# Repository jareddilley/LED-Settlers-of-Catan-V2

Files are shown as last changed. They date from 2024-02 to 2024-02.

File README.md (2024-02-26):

# LED-Settlers-of-Catan-V2


Fully 3D printed 5-6 person LED Settlers of Catan - Fully interactive game board that's fun for the whole family.

This is version two of my LED Settlers of Catan that I design and built from scratch. For those who have played Catan know that setting up the game takes a while. This board removed that with set up in an instant. Along with instant set up, the LEDs add to a great game aesthetic. This is the version 2 of the board. Version 2 is better is every way: plays up to 6 people, more compact, better aesthetics, simpler robust construction. Version 2 also has an ESP32 microcontroller so in the future I can possibly make an app that Bluetooth to the board. This GitHub contains all the code and 3D files if anyone wants to try and build their own. If you are interested in how it was build and want to be entertained at the same time, watch the YouTube video: https://www.youtube.com/watch?v=XWqmaW1D9r8

Below is the Fritzing [Schematics](https://github.com/jareddilley/LED-Settlers-of-Catan-V2/tree/main/Schematics) wiring diagram for anyone looking to build thier own.
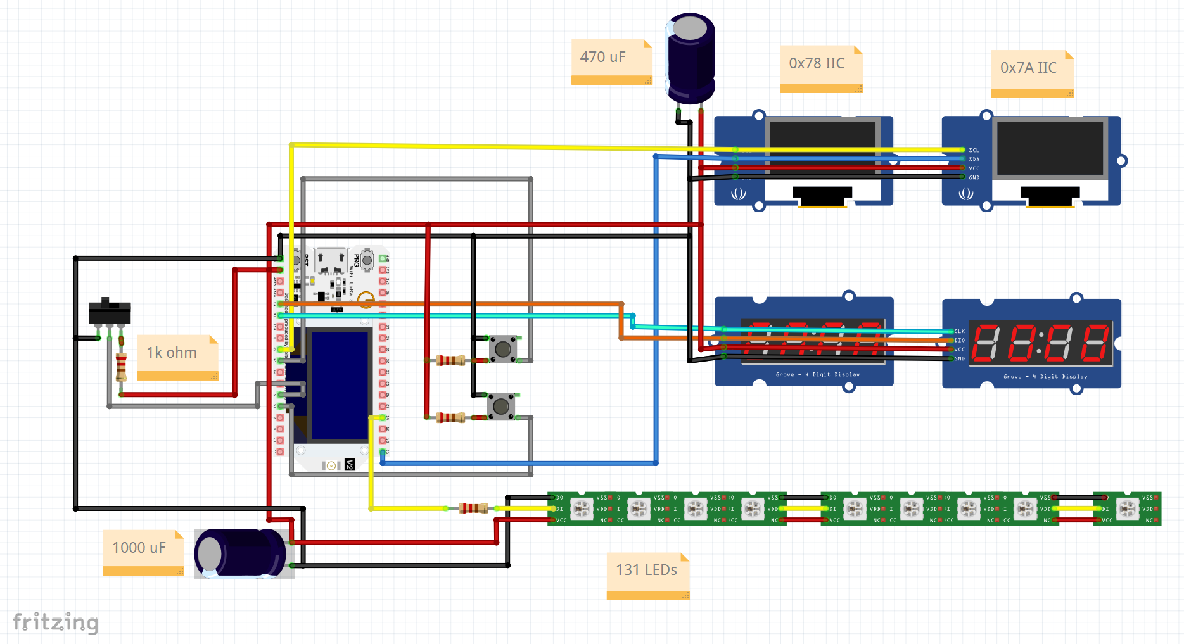
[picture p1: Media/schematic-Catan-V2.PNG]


# Game Modes


There is a switch to choose between two different game board layouts. The first mode randomly generates the game board, but makes sure no resource tile of the same type are next to each other. The second made also randomly generates the game board, but there are no restrictions and same resource types can be next to each other. The game modes can only be changed before powering up the board. The switch allows people to choose how they want to play, and it also changes what happens when a 7 is rolled. 

# Rolling a 7


With this new board, I chose to remove the idea of the robber. In addition to no robber, there is also a new hexagon that replaces one of the deserts. The hexagon is purple and allows you to choose a resource when the number on the spot is rolled. Now when a seven is rolled it changes the location of the desert and the all hex. For the evenly spread out game mode, the desert and the all hex switch places. For the fully random game mode, the desert and the all spot trade places with a random spot on the board. This changes the way the board is played, either setting people back or allowing them to pull forward. This also reduces anger between players since you can't get picked on by the robber. 

# Graphical Displays


The version 2 upgraded the pre-existing info displays. Version 1 of the board had a list of each resource and how much each has been rolled. Version 2 has two graphical displays. One is a bar char that shows the resources rolled, and the other is a bar chart showing the distribution of the dice rolls. These graphical displays add stats that allow you to see which dice rolls are being favored and which resources are dominating. 

# LED PCBs
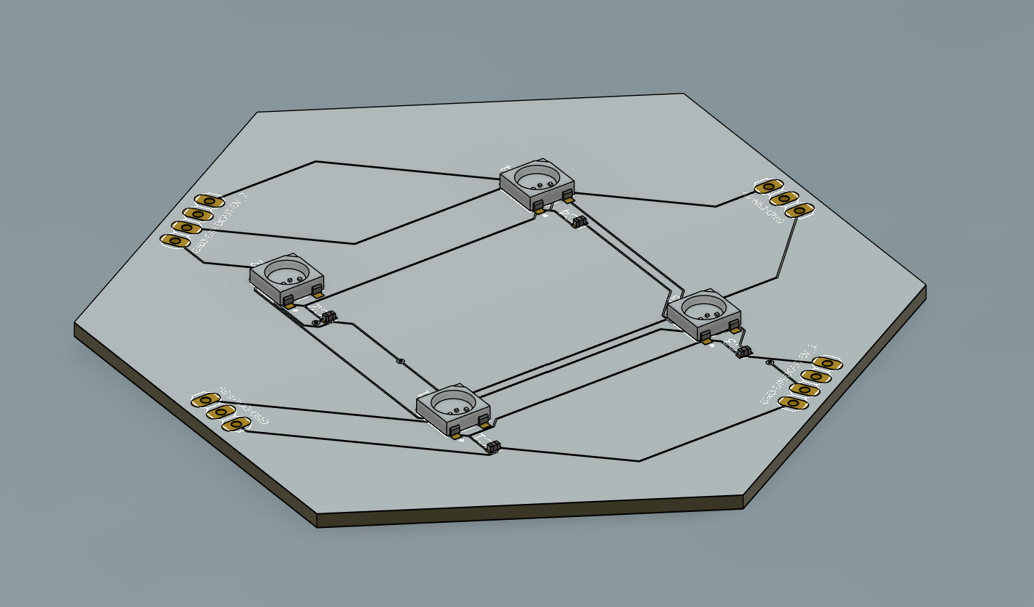
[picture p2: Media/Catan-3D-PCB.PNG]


Building these boards from scratch takes a lot of time. Version 1 used LED strips for the lighting that was very time-consuming to wire up. In this build, I went with designing my own PCBs for the LEDs that allowed for quick and easy assembly. The new PCB are white, which allows them to be LEDs and reflectors in one. I ordered my PCBs from JLCPCB, so if anyone is interested in ordering the same design, I put the zipped folder in the [Schematics](https://github.com/jareddilley/LED-Settlers-of-Catan-V2/tree/main/Schematics) directory.

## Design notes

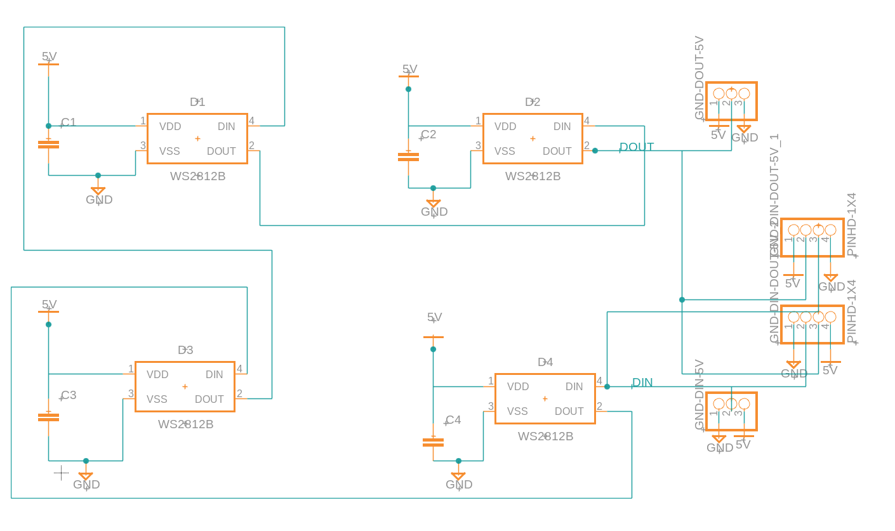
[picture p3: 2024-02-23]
Media/Catan-PCB-schematic.PNG

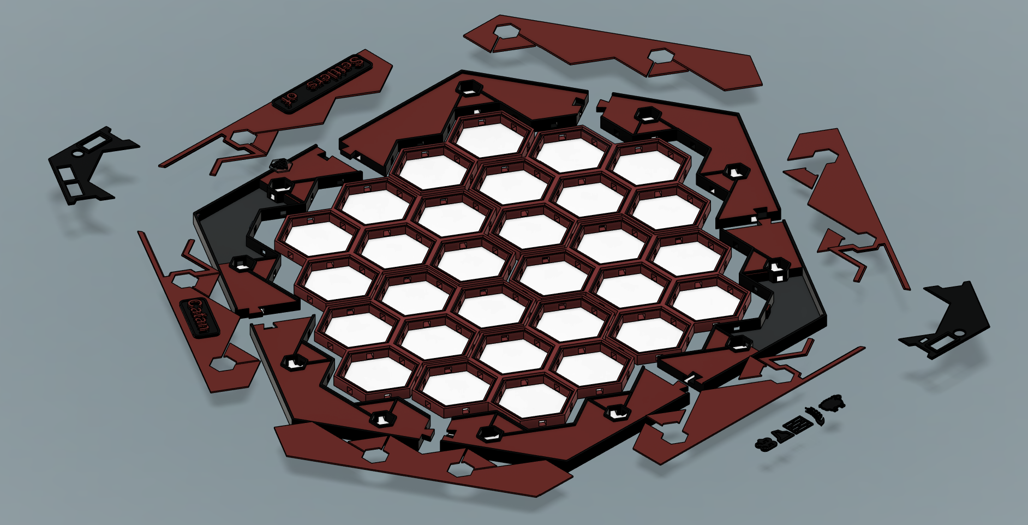
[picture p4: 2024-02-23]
Media/Catan-Fusion360.PNG

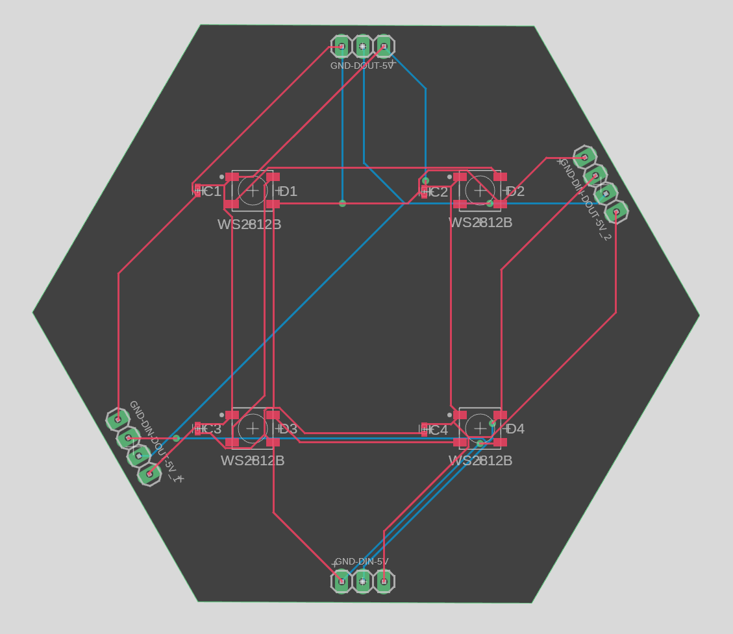
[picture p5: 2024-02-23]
Media/Catan-2D-PCB.PNG

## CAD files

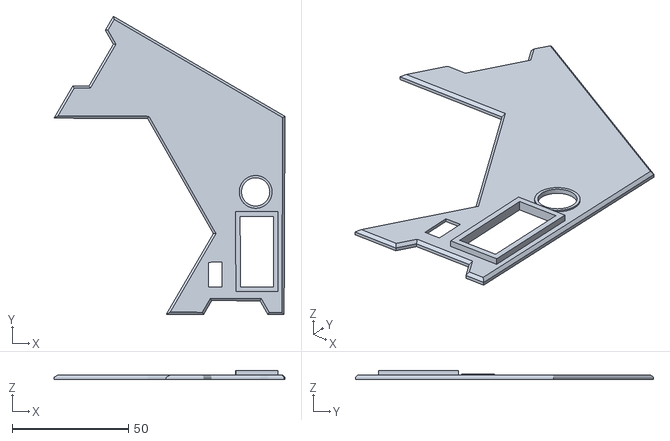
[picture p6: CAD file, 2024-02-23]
STL files/Boarders/cover-main.stl
99.6 x 128.6 x 4.00

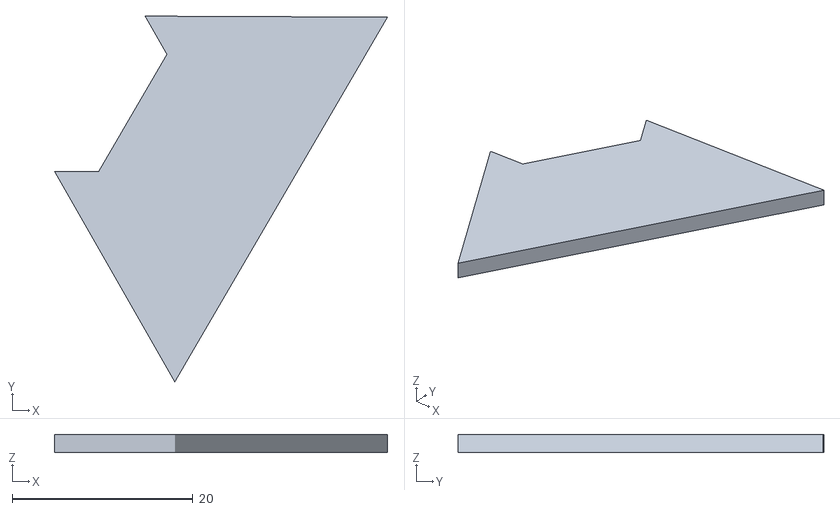
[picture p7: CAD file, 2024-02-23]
STL files/Boarders/Water-2 diff.stl
36.8 x 40.5 x 2.00

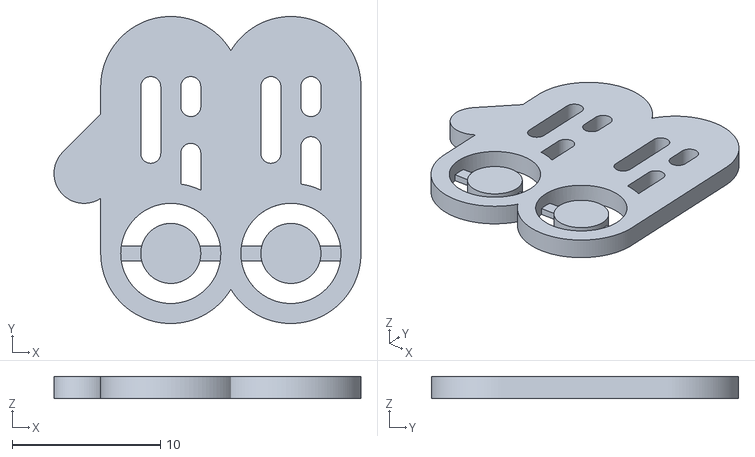
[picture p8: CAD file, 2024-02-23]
STL files/Decals/log (1).stl
20.7 x 20.7 x 1.50

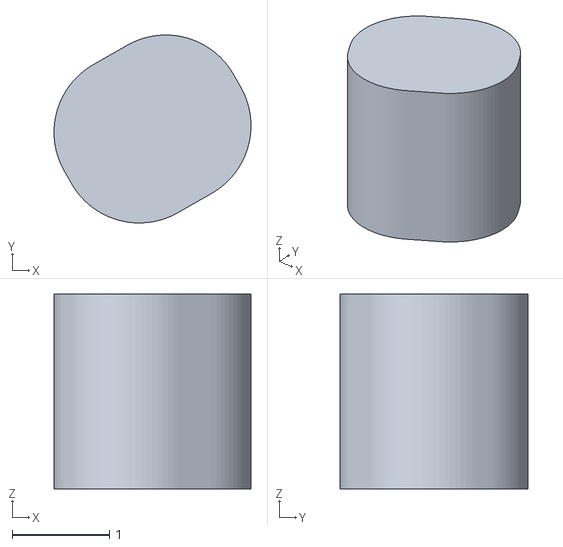
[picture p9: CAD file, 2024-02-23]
STL files/Main Board/1-Dot.stl
2.02 x 1.93 x 2.00

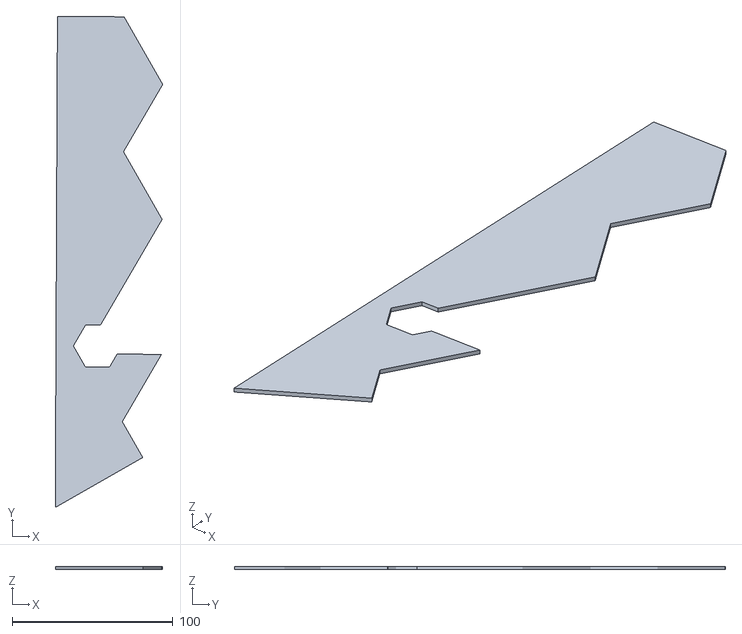
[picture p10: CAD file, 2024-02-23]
STL files/Boarders/Water-6 (1).stl
66.8 x 305.2 x 2.00

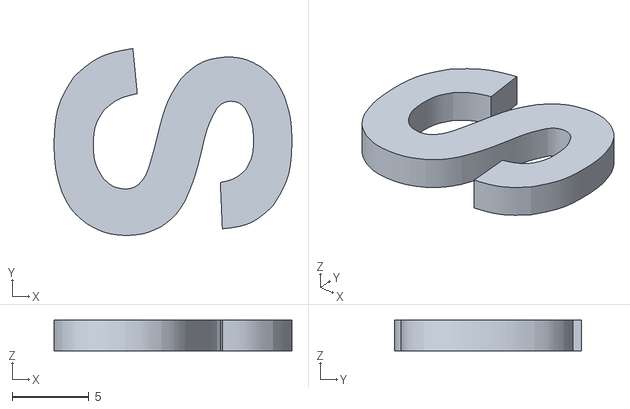
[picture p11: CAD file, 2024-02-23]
STL files/Decals/Cap S.stl
15.5 x 12.2 x 2.00

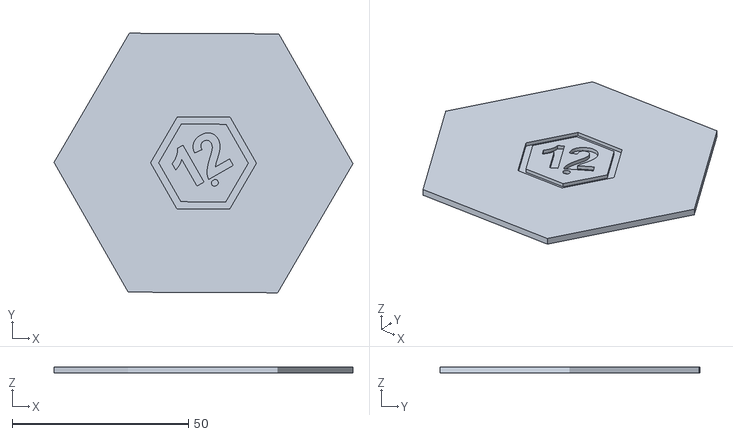
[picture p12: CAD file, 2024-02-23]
STL files/Main Board/Diffuser-12.stl
84.7 x 73.6 x 1.75

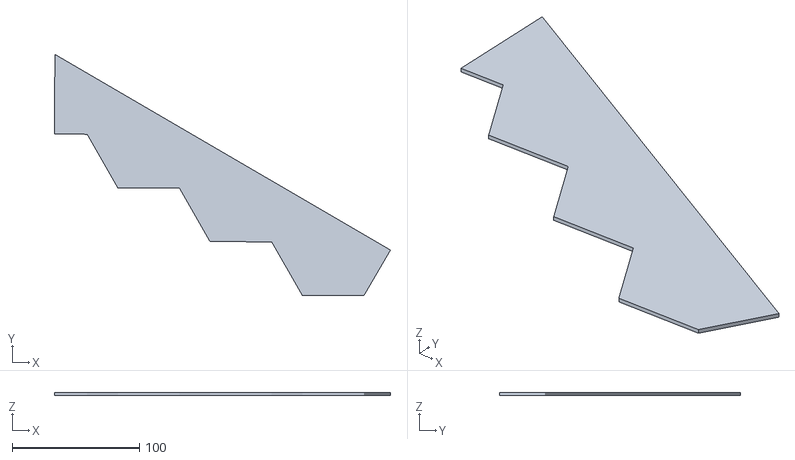
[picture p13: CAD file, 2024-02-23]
STL files/Boarders/Water-3.stl
263.9 x 189.5 x 2.00

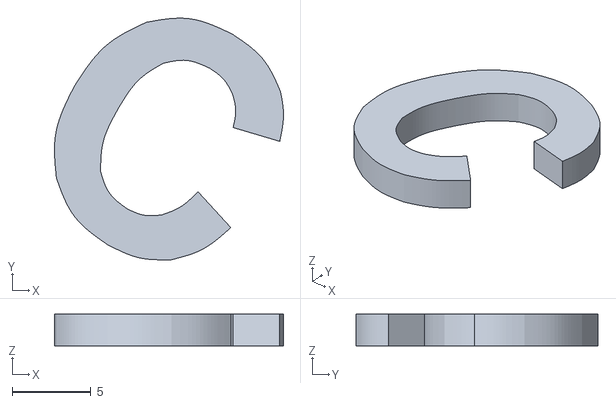
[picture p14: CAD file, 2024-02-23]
STL files/Decals/C.stl
14.5 x 15.3 x 2.00

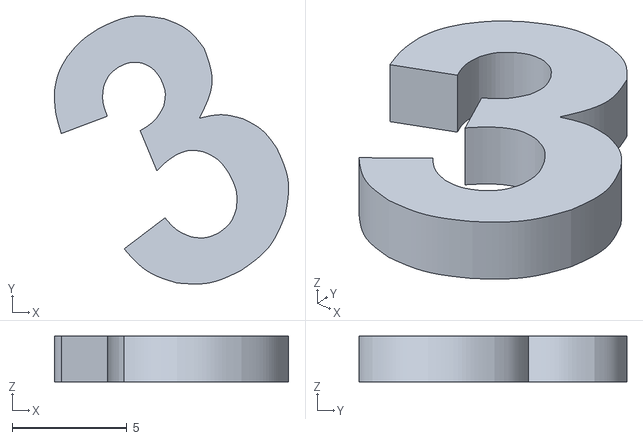
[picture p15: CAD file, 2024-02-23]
STL files/Main Board/3.stl
10.2 x 11.7 x 2.00

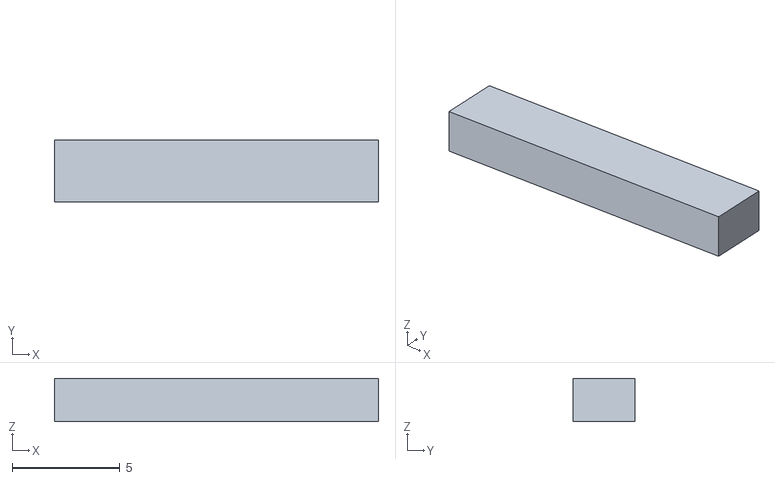
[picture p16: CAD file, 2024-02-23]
STL files/Decals/l.stl
15.0 x 2.88 x 2.00

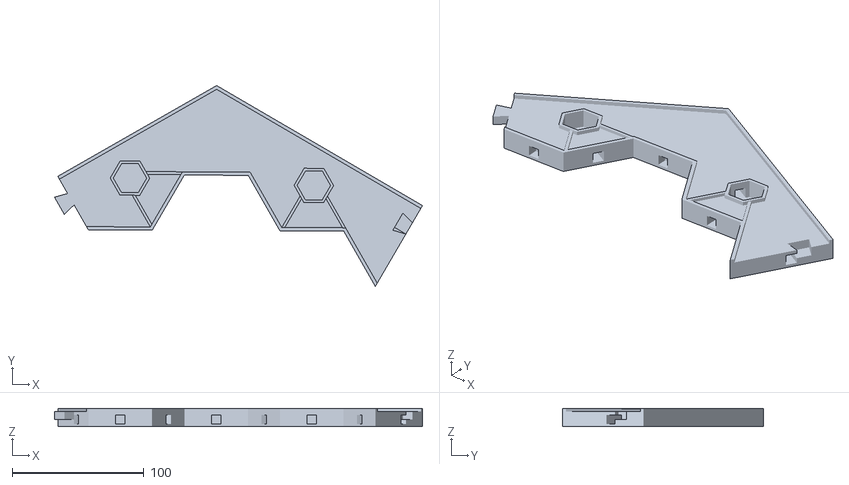
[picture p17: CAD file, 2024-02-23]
STL files/Boarders/Boarder-2.stl
279.2 x 152.5 x 14.0

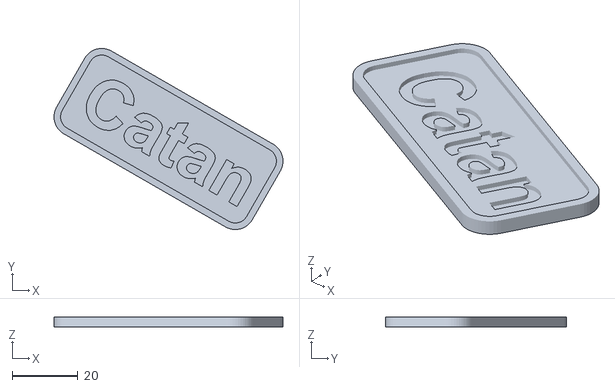
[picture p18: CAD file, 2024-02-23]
STL files/Decals/Catan.stl
69.8 x 55.2 x 3.00

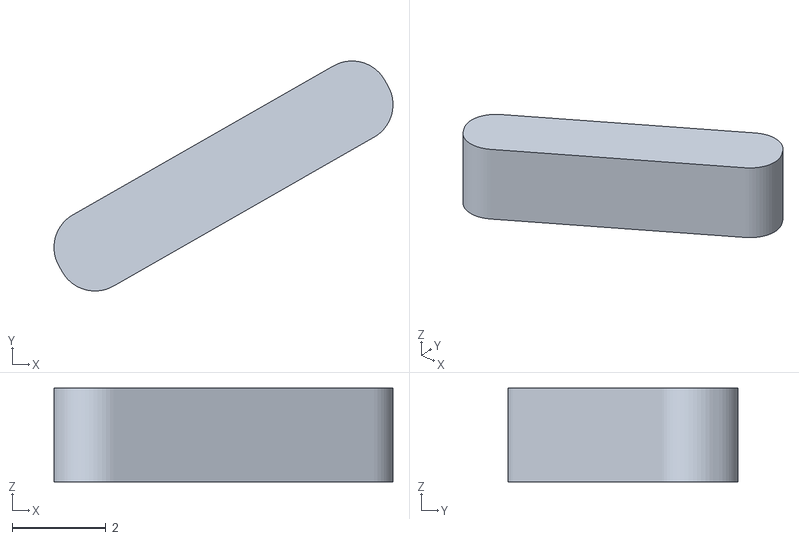
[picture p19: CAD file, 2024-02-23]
STL files/Main Board/4-Dot.stl
7.23 x 4.90 x 2.00

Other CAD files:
STL files/Main Board/Diffuser-3.stl
STL files/Decals/Boat.stl
STL files/Main Board/Diffuser-4.stl
STL files/Boarders/cover-other.stl
STL files/Boarders/Boarder-1 (1).stl
STL files/Boarders/Boarder-1.stl
STL files/Boarders/Boarder-2 (1).stl
STL files/Boarders/Boarder-3 (1).stl
STL files/Boarders/Boarder-3.stl
STL files/Boarders/Water-1.stl
STL files/Boarders/Water-2.stl
STL files/Boarders/Water-3 (2).stl
STL files/Boarders/Water-4.stl
STL files/Boarders/Water-5 (1).stl
STL files/Boarders/Water-5-other.stl
STL files/Boarders/Water-5.stl
STL files/Boarders/Water-6 (1)-other.stl
STL files/Decals/Port-Diffuser.stl
STL files/Decals/Settlers of.stl
STL files/Decals/a.stl
STL files/Decals/brick (1).stl
STL files/Decals/e.stl
STL files/Decals/f.stl
STL files/Decals/n.stl
STL files/Decals/o.stl
STL files/Decals/r.stl
STL files/Decals/rock (1).stl
STL files/Decals/s.stl
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

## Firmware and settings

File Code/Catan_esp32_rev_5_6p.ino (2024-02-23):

/**
Version 2 LED Catan - 5-6 person board size with desert included in board generation
Inludes additional rules and game aspects and a new resoruce hex (the all recource spot)
Board - 38 Pin ESP32 (Wi-fi and Bluetooth capable)
Author - Jared Dilley
**/

#include <FastLED.h>
#include <TM1637.h>
#include <SPI.h>
#include <Wire.h>
#include <Adafruit_GFX.h>
#include <Adafruit_SSD1306.h>
#include <stdlib.h>
#include <time.h>
#include <stdio.h>

#define SCREEN_WIDTH 128 // OLED display width, in pixels
#define SCREEN_HEIGHT 32 // OLED display height, in pixels
#define OLED_RESET -1 // Reset pin # (or -1 if sharing Arduino reset pin)
#define NUM_LEDS 131  // Total num of LEDs
#define spotSize 4  // num of LEDs per hex
#define LED_PIN 14
#define Button 19   // Roll Dice Button 1
#define Button2 15  // Roll Dice Button 2   
#define Mode 5      // Switch for game mode
int ButtonState;
int ButtonState2;
int brightness = 50;
const int range = 30; // number of hexagons
const int num_ports = 11;  // number of ports
int tracker = 0;
unsigned long now = millis();
int CLK = 1;
int DIO = 3;  
TM1637 tm(CLK,DIO); // TX, RX
Adafruit_SSD1306 display1(-1);  // SCL P22, SDA P21
Adafruit_SSD1306 display2(-1);
int offset = 8;
int offset2 = 7;
int brick = 0; 
int wheat = 0; 
int wood = 0; 
int rock = 0; 
int sheep = 0;
int ModeState;
int rolls[11] = {0,0,0,0,0,0,0,0,0,0,0};  // tracker for the dice rolls 2-12
int button_display[12] = {0,1,2,3,4,14,15,25,26,27,28,29};
int button2_display[12] = {26,27,28,29,21,20,9,8,0,1,2,3};



// Brick::Red, Boulder::Aqua, Logs::Green, Hay::Orange, Sheep::white, Desert::Black
uint32_t resource[range];
uint32_t resource_rand[range] = {CRGB::Red,CRGB::Red,CRGB::Red,CRGB::Red,CRGB::Red,CRGB::Aqua,CRGB::Aqua,CRGB::Aqua,CRGB::Aqua,CRGB::Aqua,
CRGB::Green,CRGB::Green,CRGB::Green,CRGB::Green,CRGB::Green,CRGB::Green,CRGB::Orange,CRGB::Orange,CRGB::Orange,CRGB::Orange,CRGB::Orange,CRGB::Orange,
CRGB::White,CRGB::White,CRGB::White,CRGB::White,CRGB::White,CRGB::White,CRGB::Black,CRGB::Purple};
uint32_t resource_spread[range] = {3,4,2,3,5,4,3,5,1,2,4,1,CRGB::Black,2,4,1,5,3,5,CRGB::Purple,1,3,2,1,4,2,5,3,4,5};
uint32_t five_spot[2] = {CRGB::Red,CRGB::Aqua};
uint32_t six_spot[3] = {CRGB::Green,CRGB::Orange,CRGB::White};
CRGB all[5] = {CRGB::Red,CRGB::Green,CRGB::Orange,CRGB::Aqua,CRGB::White};
int values[range] = {11,12,9,8,9,2,4,10,6,12,11,8,5,6,3,5,12,4,2,9,4,2,3,10,8,10,3,11,6,5}; // values of all 30 spots
int spotValues[range];
CRGB leds[NUM_LEDS];
CRGB currentColors[range];

// Function to swap two elements in an array
void swap_uint(uint32_t  *a, uint32_t  *b) {
    uint32_t  temp = *a;
    *a = *b;
    *b = temp;
}

// Function to the elements in a given array
void shuffle(uint32_t arr[], int size){
  for (int i = size - 1; i > 0; i--) {
    // Generate a random index between 0 and i (inclusive)
    int j = random(0,1000) % (i + 1);
    // Swap current element with randomly generated element
    swap_uint(&arr[i], &arr[j]);
  }
}

// Function to find an element in an array and swap it with a random element
void swapWithRandom(CRGB arr[], int size, CRGB target) {
  // Search for the target element in the array
  int found = 0;
  int targetIndex;
  for (int i = 0; i < size; i++) {
    if (arr[i] == target) {
      targetIndex = i; // Store the index of the target element
      found = 1;
      break;
    }
  }
  // If the target element was found, swap it with a random element
  if (found) {
    int randomIndex = random(0,1000) % size;
    CRGB target_spot = currentColors[targetIndex];
    CRGB rand_spot = currentColors[randomIndex];
    for (int i = 0; i < 2; i++) {  
      setSpot(targetIndex + 1, CRGB::Black, false);
      setSpot(randomIndex + 1, CRGB::Black, false);
      FastLED.show();
      delay(250);
      setSpot(targetIndex + 1, target_spot, false);
      setSpot(randomIndex + 1, rand_spot, false);
      FastLED.show();
      delay(250);
    }
    for (int i = 0; i < 2; i++) {  
      setSpot(targetIndex + 1, CRGB::Black, false);
      setSpot(randomIndex + 1, CRGB::Black, false);
      FastLED.show();
      delay(250);
      setSpot(targetIndex + 1, rand_spot, true);
      setSpot(randomIndex + 1, target_spot, true);
      FastLED.show();
      delay(250);
    }
  }
}

// Sets the specified hexagon, with an option to save changes to memory
void setSpot (int spot, CRGB color, boolean save){  
    int currentLED = (spot - 1)*spotSize + num_ports;
    int lastLED = currentLED + spotSize; 
    for (currentLED; currentLED < lastLED; currentLED++) {   
      leds[currentLED] = color;
    }
    if (save){
      currentColors[spot-1] = color; 
    }
}

// Returns True if element in array
boolean arrayIncludeElement(int randArray[], int input, int range) {
  for (int i = 0; i < range; i++) {   
    if (randArray[i] == input) {
      return true;
    }
  }
  return false;
}

// Fuction for rolling the dice and playing animations
void rollDice() {
  // Roll dice
  int roll = random(1,7) + random(1,7);
  // roll = 7; // uncomment for testing 7's
  rolls[roll-2]++;
  tm.init(); // clear
  if (roll < 10){
    tm.display(3,roll);
  } else{
    tm.display(2,1);
    tm.display(3,roll-10);
  }
  // show dice value
  for (int i = 0; i < range; i++) {   
    setSpot(i+1, CRGB::Black, false);
  }
  FastLED.show();  
  
  for (int i = 0; i < roll; i++) {   // rev
    if(ButtonState == LOW){
      setSpot(button_display[i]+1, CRGB::White, false);
    } else if (ButtonState2 == LOW){
      setSpot(button2_display[i]+1, CRGB::White, false);
    }
    FastLED.show();
    delay(100);
  }
  delay(500);
  // show only spots with that roll
  int locations[range];
  int count = 0;
  if (roll == 7){
    updateDisplay(brick, wheat, wood, rock, sheep);
    for (int a = 0; a < 3; a++) {
      for (int i = 0; i < range; i++) {   
        setSpot(i+1, CRGB::Red, false);
      }
      FastLED.show();
      delay(500);
      if (a < 2){
        for (int i = 0; i < range; i++) {   
          setSpot(i+1, CRGB::Black, false);
        }
        FastLED.show();
        delay(500);
      }
    }
    if (ModeState == HIGH){ // randomly swap desert and all piece with a random piece
      swapWithRandom(currentColors, range, CRGB::Black);
      swapWithRandom(currentColors, range, CRGB::Purple);
    } else{ // swap desert and all rec in even spread
      CRGB spot_19 = currentColors[19];
      CRGB spot_12 = currentColors[12];
      for (int i = 0; i < 2; i++) {  
        setSpot(19 + 1, CRGB::Black, false);
        setSpot(12 + 1, CRGB::Black, false);
        FastLED.show();
        delay(250);
        setSpot(19 + 1, spot_19, false);
        setSpot(12 + 1, spot_12, false);
        FastLED.show();
        delay(250);
      }
      for (int i = 0; i < 2; i++) {  
        setSpot(19 + 1, CRGB::Black, false);
        setSpot(12 + 1, CRGB::Black, false);
        FastLED.show();
        delay(250);
        setSpot(19 + 1, spot_12, true);
        setSpot(12 + 1, spot_19, true);
        FastLED.show();
        delay(250);
      }
    }
  } else{
    for (int i = 0; i < range; i++) {   
      if (values[i] == roll){
        setSpot(i+1, currentColors[i], false);
        if (currentColors[i] == all[0]){
          brick++;
        }
        if (currentColors[i] == all[1]){
          wood++;
        }
        if (currentColors[i] == all[2]){
          wheat++;
        }
        if (currentColors[i] == all[3]){
          rock++;
        }
        if (currentColors[i] == all[4]){
          sheep++;
        }
      }
      else{
        setSpot(i+1, CRGB::Black, false);
      }
    }
    updateDisplay(brick, wheat, wood, rock, sheep);
    FastLED.show();
    delay(5000);
  }
  // reset board
  for (int i = 0; i < range; i++) {   
    setSpot(i+1, currentColors[i], true);
  }
  FastLED.show();
}

// Fuction in charge of updating both OLED displays for dice and recouce roll ttracking
void updateDisplay(int brick, int wheat, int wood, int rock, int sheep){
  float maxVal = 0;
  int local = 0;
  
  display2.clearDisplay();
  display2.setCursor(2, 25);
  display2.println("2 3 4 5 6 7 8 9 A B C");
  display2.drawLine(0, 23, 127, 23, WHITE);
  for (int i = 0; i < (sizeof(rolls) / sizeof(rolls[0])); i++) {
    if (rolls[i] > maxVal) {
      maxVal = rolls[i];
    }
  }
  for (int i = 0; i < (sizeof(rolls) / sizeof(rolls[0])); i++) {
    if (rolls[i] > 0) {
      int barTop = 24 - (float(rolls[i])/maxVal)*(24);
      int barHieght = (float(rolls[i])/maxVal)*(24);
      if((barTop + barHieght) != 24)
      {
        barHieght = 24 - barTop;
      }
      display2.fillRoundRect(local, barTop, 8, barHieght, 2, WHITE);
    }
    else{
      display2.fillRoundRect(local, 0, 8, 0, 2, WHITE);
    }
    local += 12;
  }
  display2.display();

  int rec[5] = {brick,wheat,sheep,wood,rock};
  maxVal = 0;
  local = 0;

  display1.clearDisplay();
  display1.setCursor(0+offset, 25);
  display1.println("Br");
  display1.setCursor(25+offset, 25);
  display1.println("Wh");
  display1.setCursor(50+offset, 25);
  display1.println("Sh");
  display1.setCursor(75+offset, 25);
  display1.println("Wo");
  display1.setCursor(100+offset, 25);
  display1.println("Ro");
  display1.drawLine(0, 23, 127, 23, WHITE);
  for (int i = 0; i < (sizeof(rec) / sizeof(rec[0])); i++) {
    if (rec[i] > maxVal) {
      maxVal = rec[i];
    }
  }
  for (int i = 0; i < (sizeof(rec) / sizeof(rec[0])); i++) {
    if (rec[i] > 0) {
      int barTop = 24 - (float(rec[i])/maxVal)*(24);
      int barHieght = (float(rec[i])/maxVal)*(24);
      if((barTop + barHieght) != 24)
      {
        barHieght = 24 - barTop;
      }
      display1.fillRoundRect(local+offset2, barTop, 12, barHieght, 2, WHITE);
    }
    else{
      display1.fillRoundRect(local+offset2, 0, 12, 0, 2, WHITE);
    }
    local += 25;
  }
  display1.display();

}

// Initialize board
void setup() {
  // set up display
  display1.begin(SSD1306_SWITCHCAPVCC, 0x3C);
  display2.begin(SSD1306_SWITCHCAPVCC, 0x3D);

  display1.ssd1306_command(SSD1306_SETCONTRAST);
  display1.ssd1306_command(128);  // brightness 0-255
  display1.clearDisplay();
  display1.setTextSize(1);
  display1.setTextColor(WHITE);

  display2.ssd1306_command(SSD1306_SETCONTRAST);
  display2.ssd1306_command(128);  // brightness 0-255
  display2.clearDisplay();
  display2.setTextSize(1);
  display2.setTextColor(WHITE);
  updateDisplay(brick, wheat, wood, rock, sheep);
  // put your setup code here, to run once:
  tm.init();
  // set brightness; 0-7
  tm.set(1);
  // init roll display to "BEEF"
  tm.display(3,0xf);
  tm.display(2,0xe);
  tm.display(1,0xe);
  tm.display(0,8);

  pinMode(Mode, INPUT);
  ModeState = digitalRead(Mode);
  if (ModeState == HIGH){ 
    memcpy(resource, resource_rand, sizeof(resource));
  }
  else{
    memcpy(resource, resource_spread, sizeof(resource));
  }

  pinMode(Button, INPUT);
  pinMode(Button2, INPUT);
  FastLED.addLeds<WS2812B, LED_PIN, GRB>(leds, NUM_LEDS);
  FastLED.setBrightness(brightness);

  // set up random board if selected
  if(ModeState == HIGH){
    int first = random(range);
    int randArray[range] = {first};
    int num = 1;
    while(num < range){
      int input = random(range);
      if (!arrayIncludeElement(randArray, input, num)){
        randArray[num] = input;
        
        num++;
      }
    }
    uint32_t temp_resource[range];
    for (int i = 0; i < range; i++) {
      temp_resource[i] = resource[randArray[i]];
    }
    memcpy(resource, temp_resource, sizeof(resource));
  }else{
    shuffle(five_spot,2);
    shuffle(six_spot,3);
    for (int i = 0; i < range; i++) {   
      if(resource[i] == 1){
        resource[i] = five_spot[0];
      }else if(resource[i] == 2){
        resource[i] = five_spot[1];
      }else if(resource[i] == 3){
        resource[i] = six_spot[0];
      }else if(resource[i] == 4){
        resource[i] = six_spot[1];
      }else if(resource[i] == 5){
        resource[i] = six_spot[2];
      }
    }
  }
  // Animated power up sequence
  for (int i = 0; i < 1; i++) { 
    for (int i = 0; i < range; i++) {   
      setSpot(i + 1, CRGB::Black, false);
    }
    FastLED.show(); 
    delay(250);
    setSpot(11 + 1, resource[11], true);
    setSpot(17 + 1, resource[17], true);
    FastLED.show(); 
    delay(250);
    setSpot(6 + 1, resource[6], true);
    setSpot(7 + 1, resource[7], true);
    setSpot(10 + 1, resource[10], true);
    setSpot(12 + 1, resource[12], true);
    setSpot(18 + 1, resource[18], true);
    setSpot(16 + 1, resource[16], true);
    setSpot(24 + 1, resource[24], true);
    setSpot(23 + 1, resource[23], true);
    FastLED.show(); 
    delay(250);
    setSpot(0 + 1, resource[0], true);
    setSpot(1 + 1, resource[1], true);
    setSpot(2 + 1, resource[2], true);
    setSpot(5 + 1, resource[5], true);
    setSpot(13 + 1, resource[13], true);
    setSpot(15 + 1, resource[15], true);
    setSpot(25 + 1, resource[25], true);
    setSpot(26 + 1, resource[26], true);
    setSpot(27 + 1, resource[27], true);
    setSpot(28 + 1, resource[28], true);
    setSpot(22 + 1, resource[22], true);
    setSpot(19 + 1, resource[19], true);
    setSpot(9 + 1, resource[9], true);
    setSpot(8 + 1, resource[8], true);
    FastLED.show(); 
    delay(250);
    setSpot(3 + 1, resource[3], true);
    setSpot(4 + 1, resource[4], true);
    setSpot(14 + 1, resource[14], true);
    setSpot(20 + 1, resource[20], true);
    setSpot(21 + 1, resource[21], true);
    setSpot(29 + 1, resource[29], true);
    FastLED.show(); 
    delay(250);
    if(ModeState == HIGH){  // set up fully random ports
      uint32_t ports[num_ports] = {CRGB::White,CRGB::Orange,CRGB::Purple,CRGB::Green,CRGB::Purple,CRGB::Red,CRGB::Purple,CRGB::Purple,CRGB::White,CRGB::Purple,CRGB::Aqua};
      shuffle(ports,num_ports);
      for (int i = 0; i < num_ports; i++) {
        leds[i] = (CRGB) ports[i];
      } 
    } else{ // set up fixed 3:1 ports and random recource ports
      uint32_t ports[6] = {CRGB::Red,CRGB::Green,CRGB::Orange,CRGB::Aqua,CRGB::White,CRGB::White};
      shuffle(ports,6);
      leds[0] = (CRGB) ports[0];
      leds[1] = (CRGB) ports[1];
      leds[2] = CRGB::Purple;
      leds[3] = (CRGB) ports[2];
      leds[4] = CRGB::Purple;
      leds[5] = (CRGB) ports[3];
      leds[6] = CRGB::Purple;
      leds[7] = CRGB::Purple;
      leds[8] = (CRGB) ports[4];
      leds[9] = CRGB::Purple;
      leds[10] = (CRGB) ports[5];
    }
    FastLED.show(); 
  }
  // Serial.begin(115200); // higher rate for ESP32
}

// Main loop
void loop() { 
  // Get status of the two buttons
  ButtonState = digitalRead(Button);
  ButtonState2 = digitalRead(Button2);
  if (ButtonState == LOW || ButtonState2 == LOW){ // roll dice when one of the buttons is clicked
    delay(250);
    rollDice();   
  }
}
